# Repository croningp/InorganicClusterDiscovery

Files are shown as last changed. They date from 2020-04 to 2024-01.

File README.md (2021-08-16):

# Inorganic Cluster Discovery
Software and hardware to accompany the publication "A Modular Programmable Inorganic Cluster Discovery Robot for the Discovery and Synthesis of Polyoxometallates"



# Software Requirements

This software requires the following:
* Python >= 3.6 ([Linux](http://docs.python-guide.org/en/latest/starting/install3/linux/) / [Windows](https://www.python.org/downloads/release/python-363/))
* [Arduino IDE](https://www.arduino.cc/en/Main/Software)
* [Arduino Command Handler](https://github.com/croningp/Arduino-CommandHandler)
* [Arduino Command Tools](https://github.com/croningp/Arduino-CommandTools)

## Python Libraries

To install all required Python libraries, run the following command: `pip install -r requirements.txt`

# Build Instructions

Instructions for building this system can be found [here.](clusterbot/hardware/BuildInstructions/BuildInstructions.pdf)

# Running The System

Information on firmware setup can be found [here.](#arduino-firmware-setup)

All the system requires to run is a `csv` file with all necessary information present, e.g

|Reaction number|W/DMA|Thionite|Acid|Co|Ni|Mn|Fe||Rxn number|
|---|---|---|---|---|---|---|---|---|---|
DSA-CB-W/TM-1|9|0.73|0.1|0.43|0|0|0||1|

## Initial Setup
* Calibrate each Peristaltic pump
    * Pre-weigh a 14ml vial
    * Each pump should run for 1 minute dispensing deionised water into a 14ml vial
    * Weigh vial after water addition
    * Do this 3 times to obtain an average flow rate for the pump
    * Repeat this for each peristaltic pump
* Add calibrations to the `calibrations` folder in `clusterbot/software/operations/constants/calibrations/`

## Executing
* Define the path of the CSV file to run in the `run_w200_synthesis.py`
* Run the script and the synthesis will commence

# Arduino Firmware Setup

The following is a description of how to set up the Arduino firmware for use with Commanduino.

## Installation
Clone the following repositories and follow the basic set up instructions within (Works with Windows/Linux)
* [Arduino Command Handler](https://github.com/croningp/Arduino-CommandHandler)
* [Arduino Command Tools](https://github.com/croningp/Arduino-CommandTools)

## Basic Setup

* Include the Command Handler and Command Manager at the top of your file and create a CommandManager instance

```C++
#include <CommandHandler.h>
#include <CommandManager.h>
CommandManager cmdMgr;
```

* Include the basic Arduino devices you will be using e.g. AccelSteppers, Servos, etc.

```C++
#include <AccelStepper.h>
#include <LinearAccelStepperActuator.h>

/* Additional Modules if necessary */
```

* Next, include the "Command" version of all your included devices from above

```C++
#include <CommandAccelStepper.h>
#include <CommandLinearAccelStepperActuator.h>
```

* Now instantiate the Arduino device objects and their Command equivalents
    * Note: The numbers are pins and these may change depending on your setup  

```C++
AccelStepper stepper1(AccelStepper::DRIVER, 54, 55);
CommandLinearAccelStepperActuator cmdStepper(stepper1, 3, 38);

/* Additional Object creation */
```

## Setup Function

Within the setup function, we use the created CommandDevice objects and add them to the manager. Each object is given a unique ID that the user specifies.

```C++
void setup() {
    /* Here, "drive_wheel" is the unique ID */
    cmdStepper.registerToCommandManager(cmdMgr, "drive_wheel");

    /* Register the remaining devices in a similar fashion */
}
```

## Loop Function

The loop function only contains single call for the manager to update. Nothing else is required here.

```C++
void loop() {
    cmdMgr.update();
}
```

# Pin Mappings

One of the most common uses of Commanduino is controlling stepper motors for movement, pumps, etc. To be able to use multiple stepper motors on a single Arduino board, a RAMPS shield is used, giving access to 5 possible motor locations and a collection of pins for other devices. Below is a list of pin mappings for using multiple stepper motors on a single RAMPS shield.

```C++
X_STEP_PIN         54
X_DIR_PIN          55
X_ENABLE_PIN       38

Y_STEP_PIN         60
Y_DIR_PIN          61
Y_ENABLE_PIN       56

Z_STEP_PIN         46
Z_DIR_PIN          48
Z_ENABLE_PIN       62

E0_STEP_PIN         26
E0_DIR_PIN          28
E0_ENABLE_PIN       24

E1_STEP_PIN         36
E1_DIR_PIN          34
E1_ENABLE_PIN       30

X_MIN_PIN          3
X_MAX_PIN          2
Y_MIN_PIN          14
Y_MAX_PIN          15
Z_MIN_PIN          18
Z_MAX_PIN          19
```

# Commanduino Setup

This platform uses the Commanduino library to facilitate all communication between the Arduino board and our Python interface.
More examples can be found [here](https://github.com/croningp/commanduino/tree/master/examples/commanddevices).

## Configuration File

Example config file:

```json
{
    "ios": [
        {
            "port": "/dev/ttyACM0"
        },
        {
            "port": "/dev/ttyACM1"
        },
        {
            "port": "/dev/ttyACM2"
        }
    ],
    "devices": {
        "wheel": {
            "command_id": "wheel",
            "config": {
                "reverted_switch": true,
                "reverted_direction": true,
                "enabled_acceleration": false,
                "speed": 12000,
                "homing_speed": 12000,
                "acceleration": 2000
            }
        },
        "module1": {
            "command_id": "modY",
            "config": {
                "add_whats_necessary_for_device": true
            }
        },
        ...

    }
}
```

### IOS

The ```ios``` key represents the USB port the Arduino port is connected to. Commanduino will scan these ports to find the appropriate Arduino attached. For a single arduino attached, the above setup for ```ios``` is sufficient but for multiple Arduinos, it is best to assign them to a single port only. This prevents clashes.  
For port names:

* Linux
    * `"/dev/ttyACM{number}"`
* Windows
    * `"COM{number}"`

### Devices

The ```devices``` key holds all the information for the devices attached to the Arduino board. In the example above, ```wheel``` and ```module1``` are the names Commanduino will use to access them. Inside the devices, we have the ```command_id``` and ```config```.
* ```command_id```
    * This is unique ID given in the Arduino file. (See [Arduino Setup](#arduino-setup))
* ```config```
    * Dependent on the device type. (See [Commanduino Device Examples](https://github.com/croningp/commanduino/tree/master/examples/commanddevices))

## Commanduino File

Example Commanduino file:

```python
import os
import sys
import json
import time
import inspect

from commanduino import CommandManager # <-- Important!

class CoreDevice(object):
    """
    Class representing a core Commanduino system.
    Allows access to the modules attached

    Args:
        config (str): path to the Commanduino config file
    """
    def __init__(self, config):
        self.mgr = CommandManager.from_configfile(config) # Creates the CommandManager with JSON configuration file

        # Can now access devices attached e.g.
        self.wheel = self.mgr.wheel
        self.module1 = self.mgr.module1
        # etc. etc.

    ...

```

# Authors

* Daniel Salley
* Graham Keenan

All software and designs were developed as members of the [Cronin Group (University of Glasgow)](http://www.chem.gla.ac.uk/cronin/)

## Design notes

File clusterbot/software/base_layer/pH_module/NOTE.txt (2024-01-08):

There is a new and improved version of the implementation of pH module. 
See Experiments Section in https://github.com/croningp/NanoDiscovery
This was an older implementation using sockets adapted from https://github.com/mischele/DRDAQ.

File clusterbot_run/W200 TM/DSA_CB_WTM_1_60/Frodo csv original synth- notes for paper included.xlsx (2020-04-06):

Reaction number | W | DMA | Thionite | Acid | Co | Ni | Mn | Fe | Result |  |  | Co | Ni | Mn | Fe | total | Reaction number | Co% | Ni% | Mn% | Fe%
DSA-CB-W/TM-1 | 5.0000 | 4.0000 | 0.7300 | 0.1000 | 0.4250 | 0.0000 | 0.0000 | 0.0000 |  |  |  | 0.4250 | 0.0000 | 0.0000 | 0.0000 | 0.4250 | DSA-CB-W/TM-1 | 100 | 0 | 0 | 0
DSA-CB-W/TM-2 | 5.0000 | 4.0000 | 0.7300 | 0.1000 | 0.3750 | 0.0250 | 0.0000 | 0.0000 |  |  |  | 0.3750 | 0.0250 | 0.0000 | 0.0000 | 0.4000 | DSA-CB-W/TM-2 | 93.75 | 6.25 | 0 | 0
DSA-CB-W/TM-3 | 5.0000 | 4.0000 | 0.7300 | 0.1000 | 0.3250 | 0.0750 | 0.0000 | 0.0000 |  |  |  | 0.3250 | 0.0750 | 0.0000 | 0.0000 | 0.4000 | DSA-CB-W/TM-3 | 81.25 | 18.75 | 0 | 0
DSA-CB-W/TM-4 | 5.0000 | 4.0000 | 0.7300 | 0.1000 | 0.2750 | 0.1250 | 0.0000 | 0.0000 |  |  |  | 0.2750 | 0.1250 | 0.0000 | 0.0000 | 0.4000 | DSA-CB-W/TM-4 | 68.75 | 31.25 | 0 | 0
DSA-CB-W/TM-5 | 5.0000 | 4.0000 | 0.7300 | 0.1000 | 0.2250 | 0.1750 | 0.0000 | 0.0000 |  |  |  | 0.2250 | 0.1750 | 0.0000 | 0.0000 | 0.4000 | DSA-CB-W/TM-5 | 56.25 | 43.75 | 0 | 0
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

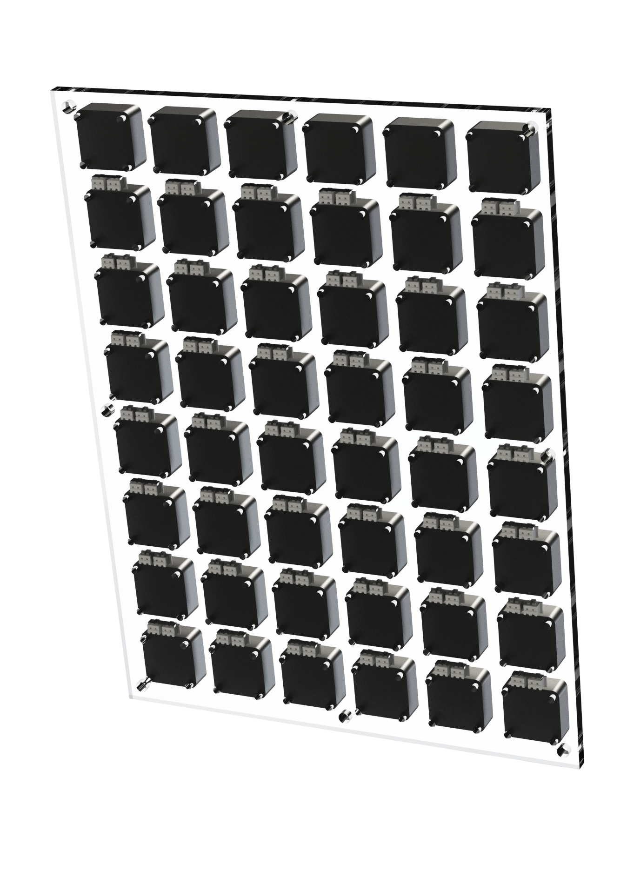
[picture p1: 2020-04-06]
clusterbot/hardware/StirringRingPCB/renders/plate_bottom_view.png

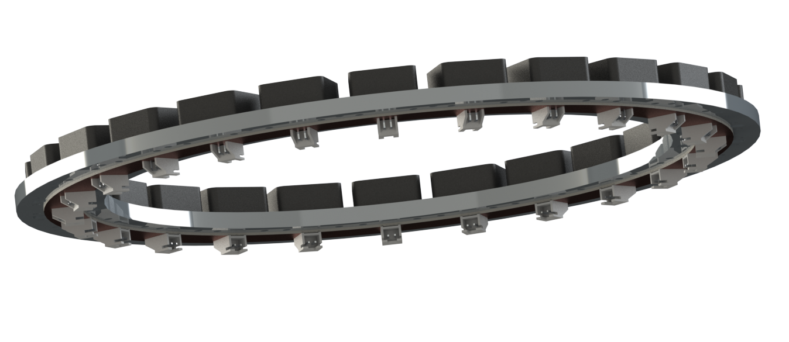
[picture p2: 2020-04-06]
clusterbot/hardware/StirringRingPCB/renders/ring_side_view.png

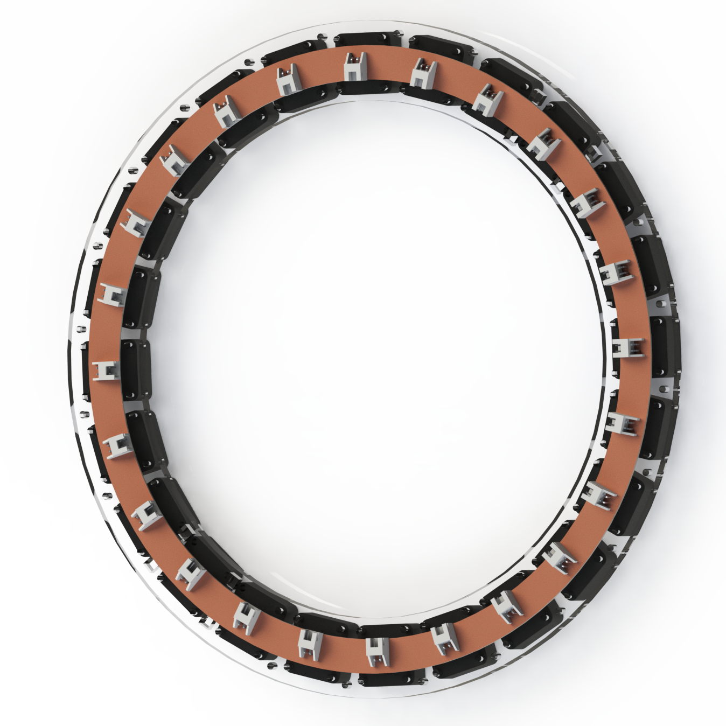
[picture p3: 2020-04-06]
clusterbot/hardware/StirringRingPCB/renders/ring_bottom_view.png

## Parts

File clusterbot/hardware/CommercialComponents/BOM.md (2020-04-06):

# Bill of Materials

This page contains a brief description of and links for the commercially available parts needed to produce this platform   

# Wheel platform

* Structural: V-slot aluminium [profile](http://ooznest.co.uk/V-Slot/Linear-Rails/V-Slot-Linear-Rail-2020mm):
  - 310 mm x 4
  - 350 mm x 4
  - 135 mm x 4
* Structural: 60 (each) M5 x 8 and 6mm [screws](http://ooznest.co.uk/Low-Profile-M5-Bolts?search=M5) with accompanying 120 [drop-in tee nuts](http://ooznest.co.uk/Drop-In-Tee-Nuts?search=drop) you will have spares
* Structural: 16 x Universal (single) L-[bracket](http://ooznest.co.uk/V-Slot/Brackets/Universal-L-Brackets)
* Structural: [Acrylic](http://www.acrylic-online.co.uk/) sheets 4mm and 6 mm (600 x 500mm minimum) x 1
* Structural: Assorted 3D printed [parts](LINK TO STL FOLDER)
* Structural: Assorted M3 x 12/16/20/30mm [screws](https://www.accu.co.uk/en/64-low-head-cap-screws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) and [nuts](https://www.accu.co.uk/en/44-thin-hexagon-nuts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)
* Structural: Slot [cover](https://ooznest.co.uk/product/slot-cover/) for organising cables and tubes
* Electronic: Arduino mega 2560 and [RAMPS](https://ooznest.co.uk/product/ramps-14-controller-board/) 1.4 with a [DRV8825](https://ooznest.co.uk/product/drv8825-stepper-motor-driver/) driver for each motor you intend to use. The options for the Arduino is included in the drop down menu options x 1
* Electronic: 25 x 25 x 10 mm DC [fans](http://ooznest.co.uk/12V-DC-25mm-Fan?search=25mm). 24 for the platform stirring ring and 48 for the stirring mantle. For each fan you will need a JST housing pair, [male](https://uk.rs-online.com/web/p/pcb-headers/8201582/) and [female](https://uk.rs-online.com/web/p/pcb-connector-housings/8201611/), using these JST [crimps](https://uk.rs-online.com/web/p/pcb-connector-contacts/8201529) for powering the fans via the PCB [ring](LINK).
* Electronic: Crimping [tool](https://www.crimpingtools.com/products/iwiss-xh2-54-3-96-ph2-0-px-kk254-jst-molex-dupont-d-sub-terminal-crimping-tool-sn-01bm-rachet-crimper-awg28-20-0-08-0-5mm) specific to the fan assemblies 
* Electronic: For simple electrical connections eg between the power supple and RAMPs board any crimp/ crimp housing conncetion can be used. We use simple Molex housings for crimps: [male](https://uk.rs-online.com/web/p/pcb-connector-housings/4841811/) and [female](https://uk.rs-online.com/web/p/pcb-connector-housings/4841748/) with accompanying crimps: [male](https://uk.rs-online.com/web/p/pcb-connector-contacts/6706316/) and [female](https://uk.rs-online.com/web/p/pcb-connector-contacts/6706307/)
* Electronic: Corsair SF450 [power supply](https://www.amazon.co.uk/Corsair-SF450-Fully-Modular-Supply/dp/B01CR5XJR6) x 1
* Electronic: Nema17 stepper x 1 [motor](https://www.omc-stepperonline.com/nema-17-bipolar-45ncm-64oz-in-2a-42x42x40mm-4-wires-w-1m-cable-and-connector.html) with accompanying Pololu aluminium mounting [hub](https://www.pololu.com/product/1998) (this part joins the drive wheel to the stepper motor shaft) x1
* Electronic: 4-wire Molex [female](https://uk.rs-online.com/web/p/pcb-connector-contacts/0467598/) crimps and [housings](https://uk.rs-online.com/web/p/pcb-connector-housings/6795375/) for Stepper motors, both pumps and drive wheel.  
* Electronic: Any 2 and 4 way crimp housings. It matters that the crimps match the plastic housings you chose, beyond that many types can be used.
* Electronic: Stepper motor to RAMP connection [housings](https://uk.rs-online.com/web/p/products/2964956/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) x 1 per stepper motor (use with appropriate crimps for this housing)
* Pumps: Gardener denver SR10-30 series, 24V stepper motor driven peristaltic [pumps](https://www.gardnerdenver.com/en-us/thomas/peristaltic-liquid-pumps/sr-10-30-series)
* Pumps: Tubing and connectors from Kinesis/Cole-Palmer:
  - [1/8mm](https://kinesis.co.uk/tubing-tubing-ptfe-1-8-3-2mm-od-x-1-5mm-id-10m-008t32-150-10.html) OD PTFE tubing
  - [1/16mm](https://kinesis.co.uk/tubing-tubing-ptfe-1-16-1-6mm-od-x-0-8mm-id-20m-008t16-080-20.html) OD PTFE tubing
  - Idex flangeless fittings Nat PP [1/8](https://www.idex-hs.com/store/fluidics/fluidic-connections/fittings/flat-bottom-fittings/flangeless-fitting-natural-polypropylene-1-4-28-flat-bottom-for-1-8-od.html)
  - Idex flangeless fittings Nat PP [1/16](https://www.coleparmer.co.uk/i/idex-xp-245-flangeless-fitting-standard-knurl-natural-pfa-1-16-od-tubing-1-4-28-flat-bottom-1-ea/0202080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)
  - Idex 1/4-28 female to male [Luer](https://www.coleparmer.co.uk/i/idex-p-675-threaded-luer-adapter-red-etfe-natural-pp-0-050-bore-male-luer-lock-x-female-1-4-28-flat-bottom-1-ea/0201421) barbed luer fittings to suite the peristaltic pump tubing and the make fitting on these Idex 1/4-28 Luers. 
  - MasterFlex fittings, PP, straight female [Luer](https://www.coleparmer.co.uk/i/masterflex-fitting-polypropylene-straight-female-luer-to-hose-barb-adapter-3-32-25-pk/4550802) with barbed adaptor. Given the peristalitc pump tubing can differ in size based on the flow rate, you will need to buy these with the appropriately barded fitting to fit the tubing, this is the one we have used for 4 mL/min flow rate peri pump heads
  - PTFE lined precision dispensing needles 25 gauge TLC lined tip [needle](https://www.nordson.com/en/divisions/efd/products/dispense-tips/ptfe-lined-tips). 
* Fan stirring [magnets](https://www.first4magnets.com/rectangular-magnets-c35/15-x-4-x-4mm-thick-n42-neodymium-magnet-2-2kg-pull-p3499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) x 30
* Stirring ring tripod [magnets](https://www.first4magnets.com/circular-disc-rod-c34/8mm-dia-x-2mm-thick-n42-neodymium-magnet-1kg-pull-p3010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|ps_1_16656)
* Driven wheel [bearing](https://uk.rs-online.com/web/p/ball-bearings/4420082/) x 1
* Modular syringe driver. The components for this part and instructions for its assembly are found [here](https://github.com/croningp/ModularSyringeDriver)

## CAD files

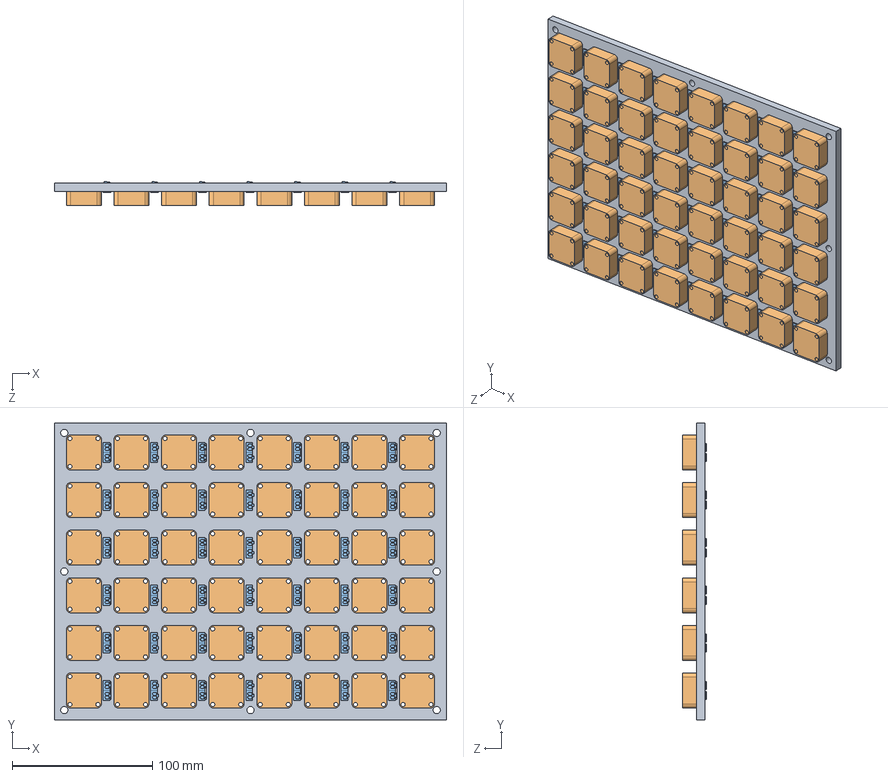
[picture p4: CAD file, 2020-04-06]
clusterbot/hardware/StirringRingPCB/plate_assembly.SLDASM
280.0 x 212.0 x 17.0 mm
plate
Fan x 48
XHP-2 x 84

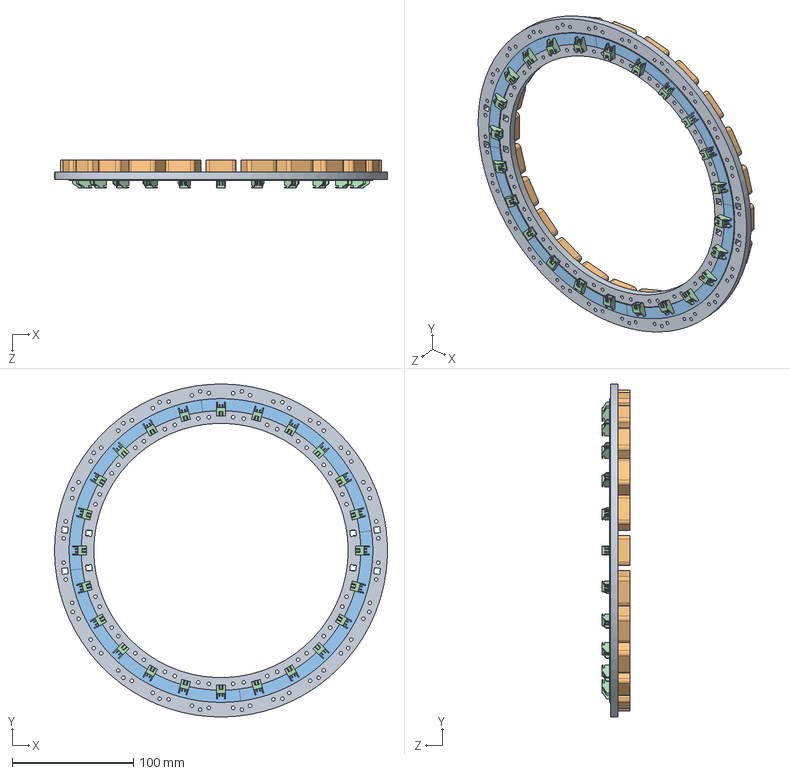
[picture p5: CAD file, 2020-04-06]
clusterbot/hardware/StirringRingPCB/ring_assembly.SLDASM
275.0 x 274.9 x 23.0 mm
ring
Fan x 24
Board^ring_assembly x 4
S2B-XH-A x 24

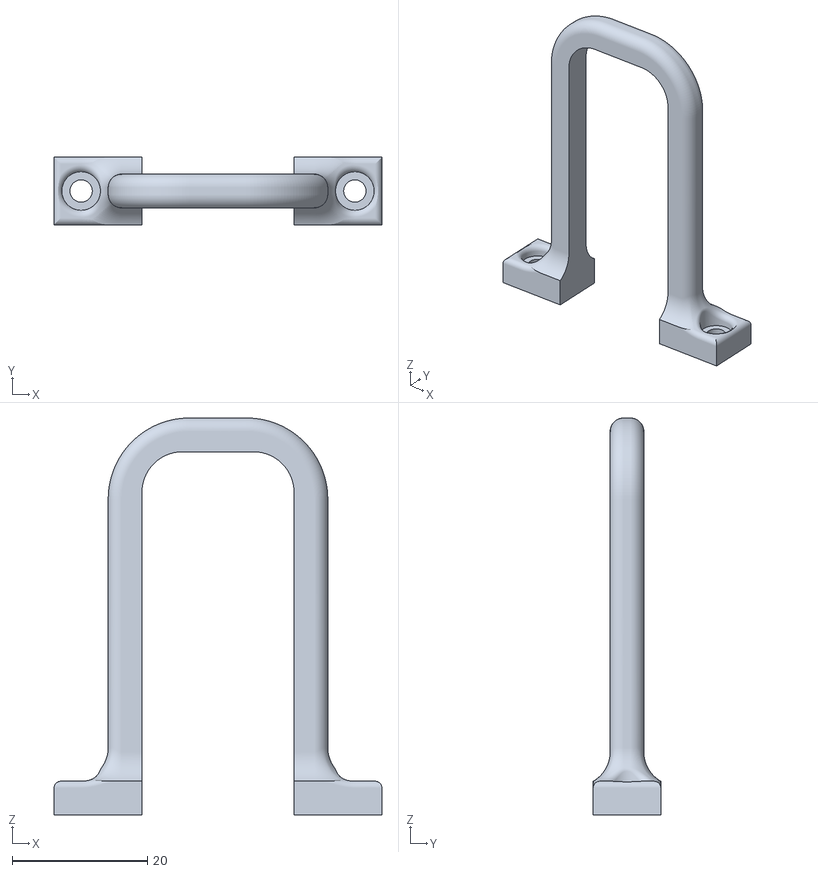
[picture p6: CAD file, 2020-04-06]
clusterbot/hardware/Prints/Base plate parts/Leveling arc - 58.75 (3).stl
48.5 x 10.0 x 58.8

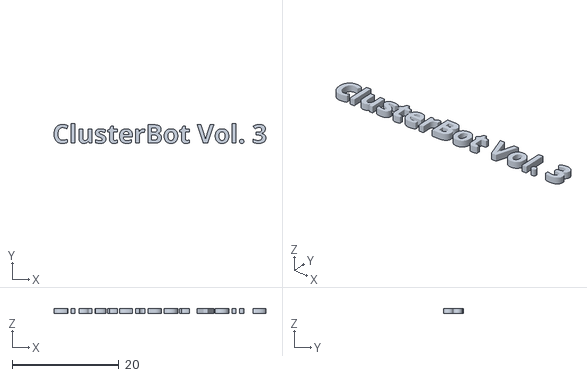
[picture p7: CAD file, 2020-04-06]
clusterbot/hardware/Prints/Dispensing unit/Kinesis needles/ClusterBot/Dispensing module Kinesis needles ClusterBot Inlay.stl
39.6 x 3.76 x 1.00

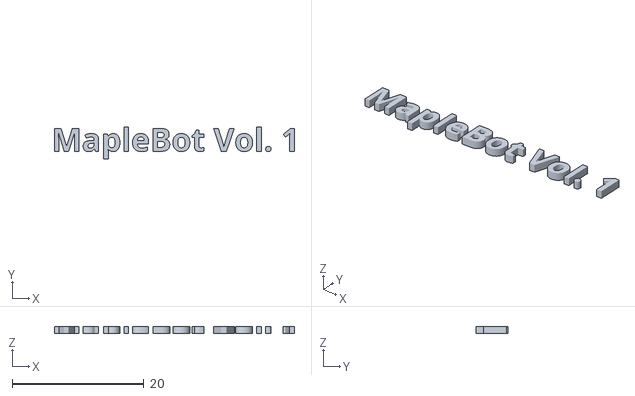
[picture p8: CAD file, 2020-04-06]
clusterbot/hardware/Prints/Dispensing unit/Kinesis needles/MapleBot/Dispensing module Kinesis needles MapleBot- inlay.stl
36.5 x 4.86 x 1.00

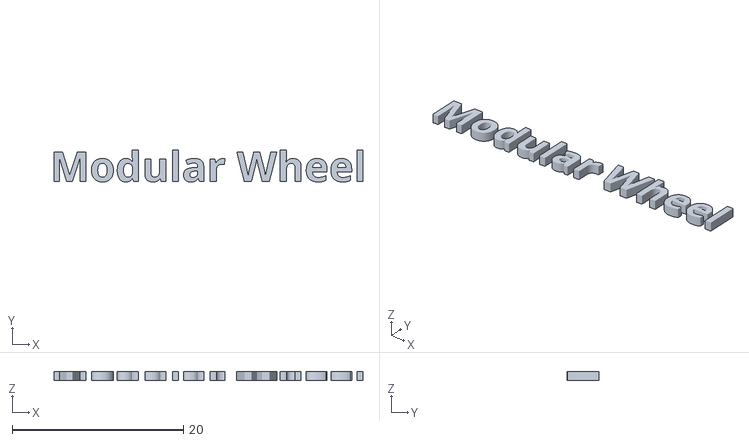
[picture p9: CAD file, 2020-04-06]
clusterbot/hardware/Prints/Dispensing unit/Kinesis needles/Modular wheel/Dispensing module 7 Kinesis needles - MW inlay.stl
36.1 x 3.74 x 1.00

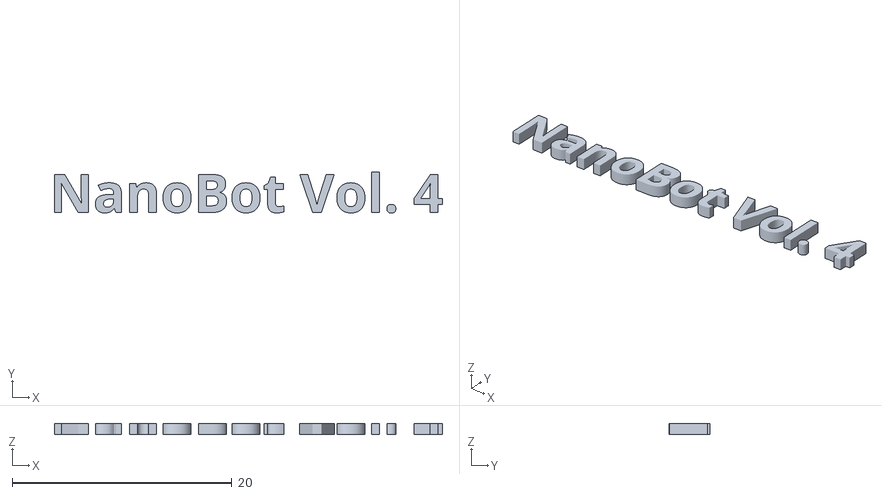
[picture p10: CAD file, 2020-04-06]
clusterbot/hardware/Prints/Dispensing unit/Kinesis needles/NanoBot/Dispensing module Kinesis needles NanoBot Inlay.stl
35.3 x 3.76 x 1.00

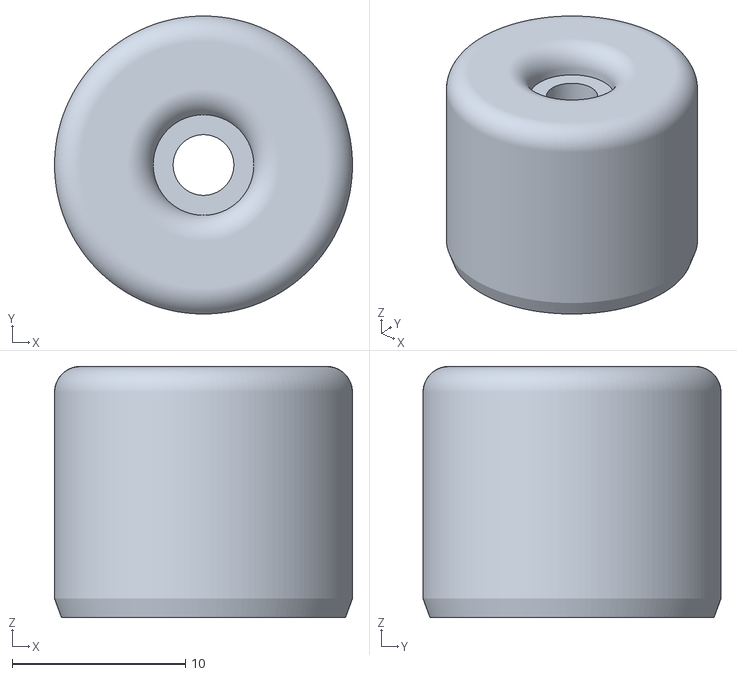
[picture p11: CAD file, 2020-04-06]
clusterbot/hardware/Prints/Dispensing unit/Raw tubes/Dispesning 7 x 1-16 raw tubes securing piece.stl
17.2 x 17.2 x 14.5

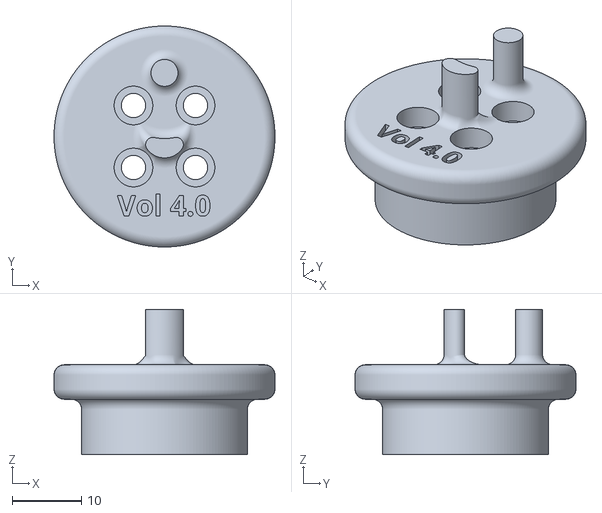
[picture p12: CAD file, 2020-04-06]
clusterbot/hardware/Prints/Drive wheel/Drive wheel.stl
32.0 x 32.0 x 21.0

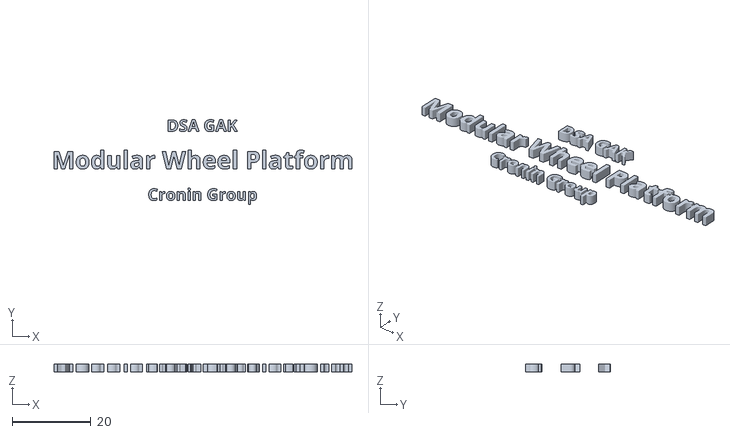
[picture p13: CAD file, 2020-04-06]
clusterbot/hardware/Prints/Driven wheel/Driven wheel Modular wheel platform- Inlay.stl
75.6 x 21.5 x 2.00

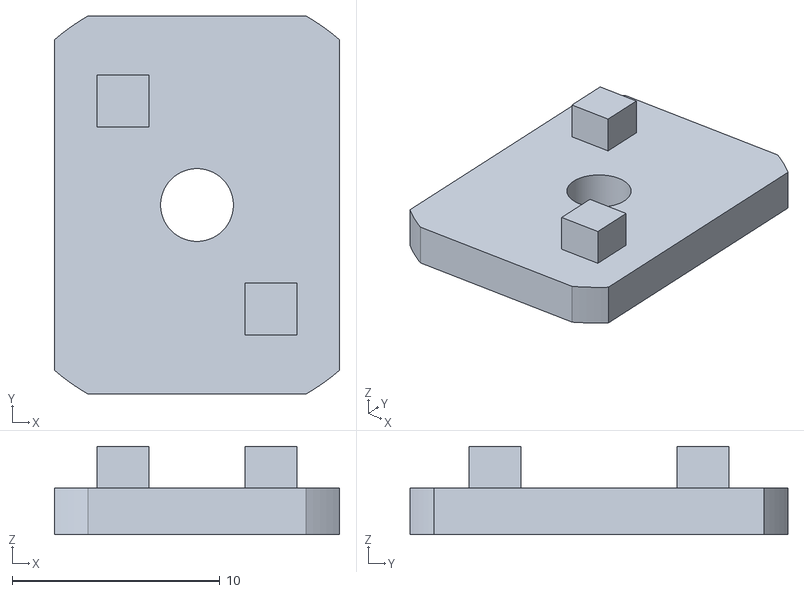
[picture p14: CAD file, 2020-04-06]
clusterbot/hardware/Prints/Stirring ring/Magnet housing base.stl
13.7 x 18.2 x 4.25

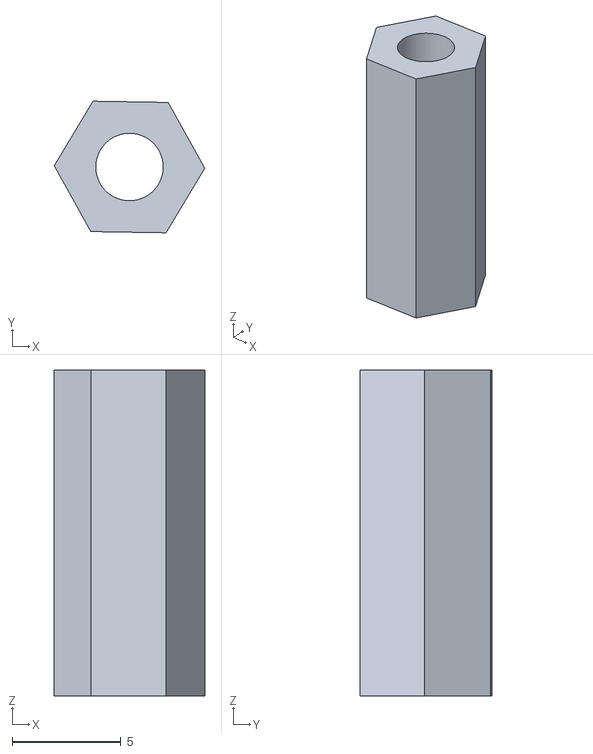
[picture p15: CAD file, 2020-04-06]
clusterbot/hardware/Prints/Vial trays/Hex spacer (3-6).stl
6.93 x 6.06 x 15.0

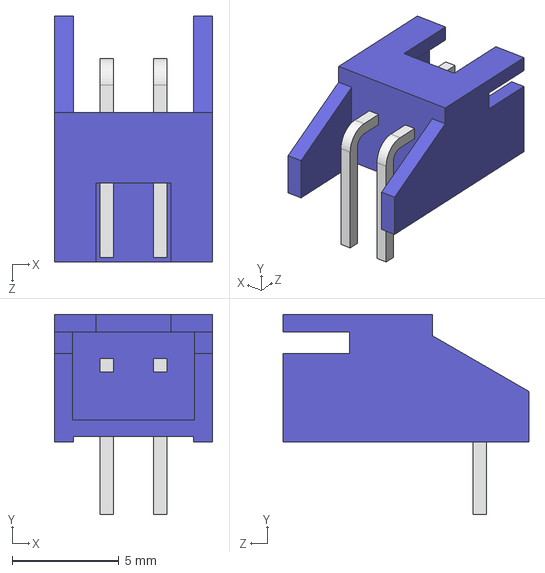
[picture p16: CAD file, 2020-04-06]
clusterbot/hardware/StirringRingPCB/parts/S2B-XH-A.STEP
7.40 x 9.35 x 11.5 mm

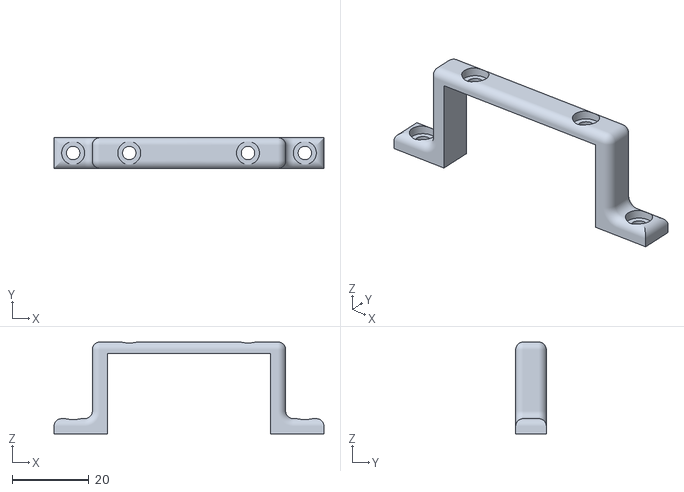
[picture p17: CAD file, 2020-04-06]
clusterbot/hardware/Prints/Base plate parts/Nema 17 Motor securing brackets (2).stl
70.5 x 8.00 x 24.0

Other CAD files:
clusterbot/hardware/Cuts/All cuts needed for one generic wheel + heating array 4mm left, 6mm right.dwg
clusterbot/hardware/Prints/Stirring ring/Magnet housing 2.2kg pull rectangular.stl
clusterbot/hardware/StirringRingPCB/parts/Fan.sldprt
clusterbot/hardware/Prints/Stirring ring/PCB mounting block.stl
clusterbot/hardware/StirringRingPCB/parts/S2B-XH-A.SLDPRT
clusterbot/hardware/StirringRingPCB/parts/XHP-2.SLDPRT
clusterbot/hardware/StirringRingPCB/parts/XHP-2.STEP
clusterbot/hardware/StirringRingPCB/parts/plate.sldprt
clusterbot/hardware/StirringRingPCB/parts/ring.sldprt

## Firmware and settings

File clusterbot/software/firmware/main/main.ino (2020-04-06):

#include <CommandHandler.h>
#include <CommandManager.h>
CommandManager cmdMgr;

/* Include the base files needed such as Accel Stepper, Servo etc */
#include <AccelStepper.h>
#include <LinearAccelStepperActuator.h>

/* Include the "Command" version of the above */
#include <CommandAccelStepper.h>
#include <CommandLinearAccelStepperActuator.h>

#include <CommandAnalogWrite.h>


/* Set up the base objects and Command objects */
AccelStepper stepperX(AccelStepper::DRIVER, 54, 55);
CommandLinearAccelStepperActuator X(stepperX, 3, 38);

AccelStepper stepperY(AccelStepper::DRIVER, 60, 61);
CommandLinearAccelStepperActuator Y(stepperY, 14, 56);

AccelStepper stepperZ(AccelStepper::DRIVER, 46, 48);
CommandLinearAccelStepperActuator Z(stepperZ, 18, 62);

AccelStepper stepperE0(AccelStepper::DRIVER, 26, 28);
CommandLinearAccelStepperActuator E0(stepperE0, 2, 24);

AccelStepper stepperE1(AccelStepper::DRIVER, 36, 34);
CommandLinearAccelStepperActuator E1(stepperE1, 15, 30);


CommandAnalogWrite PWM(8);
CommandAnalogWrite stirrer(9);


void setup() {
    Serial.begin(115200); // Always 115200

    /* Register devices to the command manager */
    X.registerToCommandManager(cmdMgr, "wheel"); 
    Y.registerToCommandManager(cmdMgr, "pH");
    Z.registerToCommandManager(cmdMgr, "R1");
    E0.registerToCommandManager(cmdMgr, "R2"); 
    E1.registerToCommandManager(cmdMgr, "R3"); 
    
    PWM.registerToCommandManager(cmdMgr, "A1");
    stirrer.registerToCommandManager(cmdMgr, "A2");

    cmdMgr.init();

}

void loop() {
    cmdMgr.update();
}
